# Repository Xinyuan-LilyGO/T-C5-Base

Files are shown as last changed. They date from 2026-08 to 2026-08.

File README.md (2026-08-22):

<div align="center" markdown="1">
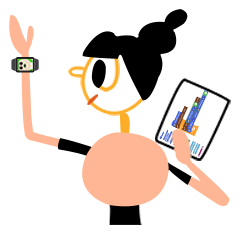
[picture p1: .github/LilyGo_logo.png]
LilyGo logo
  
</div>

<h1 align="center">LilyGo T-C5-Base</h1>

<p align="center">
  <a href="README_CN.md">中文</a>
</p>

## Contents

- [Contents](#contents)
- [Product Description](#product-description)
- [Quick Start](#quick-start)
  - [PlatformIO Quick Start](#platformio-quick-start)
  - [Arduino IDE Quick Start](#arduino-ide-quick-start)
  - [ESP-IDF Quick Start](#esp-idf-quick-start)
- [Examples](#examples)
- [Hardware Notes](#hardware-notes)
  - [CAN Pins](#can-pins)
  - [RS485 Pins](#rs485-pins)
  - [LED Pin](#led-pin)
- [Wiring Notes](#wiring-notes)
- [Speed Summary](#speed-summary)
- [Electrical Parameters](#electrical-parameters)
- [LED Description](#led-description)
- [FAQ](#faq)
  - [Why not use the official PlatformIO `platform = espressif32`?](#why-not-use-the-official-platformio-platform--espressif32)
  - [Build reports that the `t-c5-base` board cannot be found](#build-reports-that-the-t-c5-base-board-cannot-be-found)
  - [Unable to upload or flash](#unable-to-upload-or-flash)
  - [CAN reports `bus_off`, `state=passive`, or `RX=0`](#can-reports-bus_off-statepassive-or-rx0)
  - [Can CAN go above 1 Mbit/s?](#can-can-go-above-1-mbits)
  - [Why is the RS485 maximum speed 5 Mbps?](#why-is-the-rs485-maximum-speed-5-mbps)
  - [RS485 has no data or persistent bad frames](#rs485-has-no-data-or-persistent-bad-frames)
  - [Boot log reports **psram_mspi: Failed to allocate dummy cacheline for PSRAM memory barrier!**](#boot-log-reports-psram_mspi-failed-to-allocate-dummy-cacheline-for-psram-memory-barrier)
- [Resources](#resources)
  - [Schematic](#schematic)
  - [PCB Dimensions](#pcb-dimensions)

## Product Description

This repository provides Arduino and ESP-IDF test examples for the LilyGo T-C5-Base. It covers dual CAN, dual RS485, CAN speed tests, RS485 speed tests, and Modbus RTU over RS485.

Main features:

- RISC-V MCU with 2.4 and 5 GHz dual-band Wi-Fi 6, Bluetooth 5 (LE), and IEEE 802.15.4 (Zigbee, Thread)
- Non-isolated RS485 and CAN transceivers
- 7 to 40 V DC input through an XT30 connector
- Stackable expansion design, supporting up to RS485 x2 and CAN x2 at the same time
- Reserved PCB connector for a 0.96 inch OLED display
- Onboard BOOT and RST buttons
- 2 x 12 pin 2.54 mm headers
- CAN up to 1 Mbps
- RS485 up to 5 Mbps
- Removable termination resistor

## Quick Start

### PlatformIO Quick Start

> [!IMPORTANT]
>
> Do not use the official PlatformIO `platform = espressif32`. Common official PlatformIO Espressif32 releases do not correctly support the ESP32-C5 Arduino environment used by this project. Use the **pioarduino** Espressif32 platform instead.
>

1. Install [Visual Studio Code](https://code.visualstudio.com/) and the **pioarduino** extension.
2. Follow the current [pioarduino](https://github.com/pioarduino/pioarduino-vscode-ide) instructions to install the pioarduino Espressif32 platform.
3. Make sure `platformio.ini` uses the pioarduino platform and enables this repository's local board definition:

   ```ini
   [platformio]
   src_dir = examples/can_dual_speed_test
   boards_dir = board

   [env:t-c5-base]
   board = t-c5-base
   platform = https://github.com/pioarduino/platform-espressif32/releases/download/stable/platform-espressif32.zip
   framework = arduino
   upload_speed = 921600
   monitor_speed = 115200
   ```

4. Change `src_dir` in `platformio.ini` to select the example you want to build.
5. Build:

   ```bash
   pio run
   ```

6. Upload:

   ```bash
   pio run -t upload --upload-port COM76
   ```

7. Open the serial monitor:

   ```bash
   pio device monitor -p COM76 -b 115200
   ```

### Arduino IDE Quick Start

1. Install [Arduino IDE](https://www.arduino.cc/en/software).
2. Install [ESP32 Arduino core](https://docs.espressif.com/projects/arduino-esp32/en/latest/) with ESP32-C5 support.
3. Select the `ESP32C5 Dev Module` board, and set the other options according to the table below.

    | Name                                 | Value                                                |
    | ------------------------------------ | ---------------------------------------------------- |
    | Board                                | **ESP32C5 Dev Module**                               |
    | Port                                 | Your port                                            |
    | USB CDC On Boot                      | Enable                                               |
    | CPU Frequency                        | 240MHZ(WiFi)                                         |
    | Core Debug Level                     | None                                                 |
    | Erase All Flash Before Sketch Upload | Disable                                              |
    | Flash Mode                           | QIO                                                  |
    | Flash Frequency                      | 80MHz                                                |
    | Flash Size                           | **16MB(128Mb)**                                      |
    | Arduino Runs On                      | Core1                                                |
    | Partition Scheme                     | **16M Flash (3MB APP/9.9MB FATFS)**                  |
    | PSRAM                                | CAN and basic examples can use Enabled. Dual RS485 speed tests are recommended to use Disabled. |
    | Upload Speed                         | 921600                                               |

4. Open any `.ino` file under `examples/`.
5. Select the board serial port.
6. Compile and upload.

Build an example with `arduino-cli`:

```bash
arduino-cli compile -b esp32:esp32:esp32c5:CDCOnBoot=cdc,FlashSize=16M,PartitionScheme=app3M_fat9M_16MB,PSRAM=enabled examples/can_basic_echo/can_basic_echo.ino
```

> [!IMPORTANT]
>
> 1. Dual RS485 tests need USB CDC for logs because UART0/Serial0 is used by RS4851. `ARDUINO_USB_CDC_ON_BOOT=1` is already enabled in `board/t-c5-base.json`.
>
> 2. If you use only **T-C5-Base**, only the **blink** and **wifi_scan** examples in this repository are usable. CAN and RS485 examples require the matching Shield.
>

### ESP-IDF Quick Start

ESP-IDF examples are located in `idf-examples/`. The ESP-IDF version used by this project is:

- Branch: `release/v6.1`
- `ESP-IDF v6.1-dev-6068-g6a9c44fe7e`
- Git commit: `6a9c44fe7e`
- Test target: `esp32c5`
- If this is your first time using ESP-IDF, see the [ESP-IDF Programming Guide](https://docs.espressif.com/projects/esp-idf/en/release-v6.1/esp32c5/index.html).

Build on WSL/Linux:

```bash
git clone --recursive -b release/v6.1 https://github.com/espressif/esp-idf.git
cd esp-idf
./install.sh esp32c5
. ./export.sh
cd ..
git clone https://github.com/Xinyuan-LilyGO/T-C5-Base.git
cd T-C5-Base/idf-examples/idf_can_dual_basic_echo
idf.py set-target esp32c5
idf.py build
```

If the ESP-IDF environment can access the serial port directly, flash and monitor with:

```bash
idf.py -p COM76 flash monitor
```

If WSL cannot open the Windows `COMx` port directly, build with `idf.py build` in WSL first, then flash from Windows PowerShell with `esptool.exe`:

```powershell
esptool.exe --chip esp32c5 -p COM76 -b 460800 --before default-reset --after hard-reset write-flash --flash-mode dio --flash-size 16MB --flash-freq 80m 0x2000 .\build\bootloader\bootloader.bin 0x8000 .\build\partition_table\partition-table.bin 0x10000 .\build\idf_can_dual_basic_echo.bin
```

The default serial monitor baud rate is `115200`.

## Examples

Arduino examples:

| Example | Type | Description |
| --- | --- | --- |
| `examples/blink` | Basic | GPIO8 green LED blinking example. CAN/RS485 Shield is not required. |
| `examples/wifi_scan` | Basic | Wi-Fi scan example. CAN/RS485 Shield is not required. |
| `examples/can_basic_echo` | CAN | Single CAN echo. Select CAN1 or CAN2 with `ACTIVE_CAN`; received frames are sent back unchanged. Requires two boards or another CAN node for ACK. |
| `examples/can_dual_basic_echo` | CAN | Single-board dual CAN echo-back. CAN1 sends to CAN2, then CAN2 echoes back to CAN1. Supports OLED PASS/FAIL display, and GPIO8 LED blinks for 300 ms when the test passes. |
| `examples/can_speed_test` | CAN | Single CAN speed test. Normal mode requires two boards or another CAN node. |
| `examples/can_dual_speed_test` | CAN | Dual CAN mutual speed test. Connect CAN1/CAN2 on the same board to the same CAN bus for mutual TX/RX. Supports OLED status display. |
| `examples/can_advanced` | CAN | Dual CAN forwarding and diagnostics example, including filtering and bus-off recovery logic. |
| `examples/rs485_basic_echo` | RS485 | Single RS485 echo. Select RS4851 or RS4852 with `ACTIVE_RS485`; serial monitor input is sent to the RS485 bus, and bus data is printed back to serial. |
| `examples/rs485_dual_basic_echo` | RS485 | Single-board dual RS485 echo-back. RS4851 sends to RS4852, then RS4852 echoes back to RS4851. Supports OLED PASS/FAIL display, and GPIO8 LED blinks for 300 ms when the test passes. |
| `examples/rs485_speed_test` | RS485 | Single RS485 speed test. |
| `examples/rs485_dual_speed_test` | RS485 | Dual RS485 mutual speed test using Arduino `HardwareSerial` and manual DE control. |
| `examples/rs485_dual_driver_speed_test` | RS485 | Dual RS485 Arduino API speed test, used to verify the stable speed of a pure Arduino implementation. |
| `examples/rs485_modbus_module` | RS485 | Modbus RTU host example. The default function code is `0x03`. |
| `examples/can_rs485_dual_echo_back` | Combined  | Single-board dual CAN plus dual RS485 echo-back test, used to verify CAN/RS485 Shield operation at the same time. |

> [!NOTE]
>
> CAN and RS485 examples require the matching Shield. `can_dual_basic_echo`, `can_dual_speed_test`, and `can_rs485_dual_echo_back` need CAN1_H/CAN2_H and CAN1_L/CAN2_L connected to the same CAN bus, with the 120R resistor jumper installed.
>
> `rs485_dual_basic_echo`, `rs485_dual_speed_test`, and `rs485_dual_driver_speed_test` need RS4851_A/RS4852_A and RS4851_B/RS4852_B connected together. For high-speed or long-cable tests, install the 120R termination resistor jumper.

- For more ESP32-C5 examples, see [arduino-esp32-libraries](https://github.com/espressif/arduino-esp32/tree/master/libraries).

ESP-IDF examples:

| Example | Type  | Description |
| --- | ----- | --- |
| `idf-examples/idf_can_dual_basic_echo` | CAN | ESP-IDF dual CAN echo-back example. CAN1 sends to CAN2, then CAN2 echoes back to CAN1. Default `1 Mbit/s`, pure ESP-IDF TWAI on-chip API. |
| `idf-examples/idf_rs485_dual_speed_test` | RS485 | ESP-IDF dual RS485 speed test using the ESP-IDF UART RS485 driver. Tested stable at `5 Mbps` with 25 m cable and 120R termination. |

> [!NOTE]
>
> `idf_can_dual_basic_echo` was tested with `ESP-IDF v6.1-dev-6940-g08e0d30a74`, target chip `esp32c5`, and COM76. During an 18-second run, 9 echo-back tests passed with `fail=0`, `busErr=0/0`, and `isrDrop=0/0`.

## Hardware Notes

### CAN Pins

| ESP32-C5 | SN65HVD231DR |
| --- | --- |
| GPIO26 | CAN1_TX |
| GPIO25 | CAN1_RX |
| GPIO0 | CAN2_TX |
| GPIO1 | CAN2_RX |

### RS485 Pins

| ESP32-C5 | SP3485EEN |
| --- | --- |
| GPIO4 | RS4851_RX |
| GPIO5 | RS4851_TX |
| GPIO27 | RS4851_DTR / RTS |
| GPIO24 | RS4852_RX |
| GPIO23 | RS4852_TX |
| GPIO7 | RS4852_DTR / RTS |

### LED Pin

| ESP32-C5 | LED |
| --- | ----- |
| GPIO8 | Green |

## Wiring Notes

- Normal CAN mode requires at least two CAN nodes. A single CAN node has no ACK and may report TX failure or bus-off.
- `can_dual_speed_test` uses CAN1 and CAN2 on the same board as two CAN nodes. Connect CAN1_H to CAN2_H and CAN1_L to CAN2_L on the same CAN bus.
- The CAN bus needs proper termination at the physical ends. A 120R termination resistor is recommended for normal tests, especially at 500 kbit/s and 1 Mbit/s.
- By default, the onboard 120R termination resistor is already shorted by the jumper cap.
- RS485 A/B must be connected with the correct polarity. If there is no data or bad frames persist, swap A/B and test again.
- RS485 wiring should consider common ground, termination, cable length, and baud rate according to the actual site.
- The GND pin on the CAN and RS485 3-pin connector usually does not need to be connected. Connect GND if shielding or grounding is required.
- GPIO15 is not available and is not routed to the 12-pin connector. Do not control GPIO15 in software, because GPIO15 is connected to the internal PSRAM. Controlling GPIO15 may cause a crash.

## Speed Summary

| Interface | Condition | Highest stable result |
| --- | --- | --- |
| CAN | 25 m twisted pair cable, with 120R termination | 1 Mbit/s |
| CAN | 20 cm Dupont wire, without 120R termination | 125 kbit/s |
| RS485 | 25 m cable, with 120R, Arduino-ESP32 4.0.0-alpha1 | 5 Mbps |
| RS485 | 25 m cable, with 120R, ESP-IDF UART RS485 driver | 5 Mbps |

CAN has been confirmed at the standard Classic CAN rate of **1 Mbit/s**.

## Electrical Parameters

| Feature | Details |
| --- | --- |
| USB-C input voltage | 5V |
| XT30 DC input range | 7-40V |
| 3.3V header output current capability | 500mA |

> [!IMPORTANT]
>
> 1. It is not recommended to draw 2A from the 5V interface for a long time. If long-term high load is required, provide proper heat dissipation.
>
> 2. It is not recommended to connect a 40V power supply to the XT30 input. Use less than 40V. If a 40V input supply is used, make sure it is a stable voltage source, because 40V is the maximum rating of the power chip.
>
> 3. The current capability of the 5V header depends on the connected power source when USB-C is used. When XT30 is used, the maximum is 2A.
>

## LED Description

| Description | Color |
| --- | ----- |
| 3.3V power indicator | Red |
| 5V power indicator | Red |
| GPIO8 control | Green |

## FAQ

### Why not use the official PlatformIO `platform = espressif32`?

Common official PlatformIO Espressif32 releases do not correctly support the ESP32-C5 Arduino environment used by this project. Use the pioarduino Espressif32 platform.

### Build reports that the `t-c5-base` board cannot be found

Make sure `platformio.ini` contains:

```ini
boards_dir = board
board = t-c5-base
```

The local board definition file is located at `board/t-c5-base.json`.

### Unable to upload or flash

Try entering download mode manually:

1. Hold BOOT.
2. Press RST briefly.
3. Release BOOT.
4. Run the upload command again.

Also make sure the upload port is correct, for example `COM76` on Windows.

### CAN reports `bus_off`, `state=passive`, or `RX=0`

Check that CAN-H/CAN-L are connected correctly. Make sure there are at least two CAN nodes on the bus and add 120R termination resistors at both ends. In testing, a 20 cm cable without 120R was only stable up to 125 kbit/s. With 120R, it reached 1 Mbit/s.

### Can CAN go above 1 Mbit/s?

The standard Classic CAN rate is usually up to 1 Mbit/s. ESP32-C5 supports a maximum CAN communication rate of 1 Mbps.

### Why is the RS485 maximum speed 5 Mbps?

ESP32-C5 supports a maximum communication rate of 5 Mbps.

### RS485 has no data or persistent bad frames

Check A/B polarity first, then common ground, termination resistor, baud rate, and whether the correct RS485 channel is enabled in the example.

### Boot log reports **psram_mspi: Failed to allocate dummy cacheline for PSRAM memory barrier!**

```sh
ESP-ROM:esp32c5-eco3-20250704
Build:Jul  4 2025
rst:0x15 (USB_UART_HPSYS),boot:0x1e (SPI_FAST_FLASH_BOOT)
SPI mode:DIO, clock div:1
load:0x408556c0,len:0x1254
load:0x4084bba0,len:0xc20
load:0x4084e5a0,len:0x3270
entry 0x4084bba0
E (1023) psram_mspi: Failed to allocate dummy cacheline for PSRAM memory barrier!
```

- See the official note: [arduino-esp32/issues/12587](https://github.com/espressif/arduino-esp32/issues/12587)

## Resources

### Schematic

- [T-C5-Base](./schematic/T-C5-Base.pdf)
- [T-C5-CAN-Shield](./schematic/T-C5-CAN-Shield.pdf)
- [T-C5-RS485-Shield](./schematic/T-C5-RS485-Shield.pdf)

### PCB Dimensions

- [T-C5-Base SVG](./dimensions/T-C5-Base.svg)
- [T-C5-CAN-Shield SVG](./dimensions/T-C5-CAN-Shield.svg)
- [T-C5-RS485-Shield SVG](./dimensions/T-C5-RS485-Shield.svg)
- [T-C5-Base DXF](./dimensions/T-C5-Base.dxf)
- [T-C5-CAN-Shield DXF](./dimensions/T-C5-CAN-Shield.dxf)
- [T-C5-RS485-Shield DXF](./dimensions/T-C5-RS485-Shield.dxf)

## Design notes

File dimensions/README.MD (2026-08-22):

# T-C5-Base

- [T-C5-Base SVG](./T-C5-Base.svg)
- [T-C5-Base DXF](./T-C5-Base.dxf)

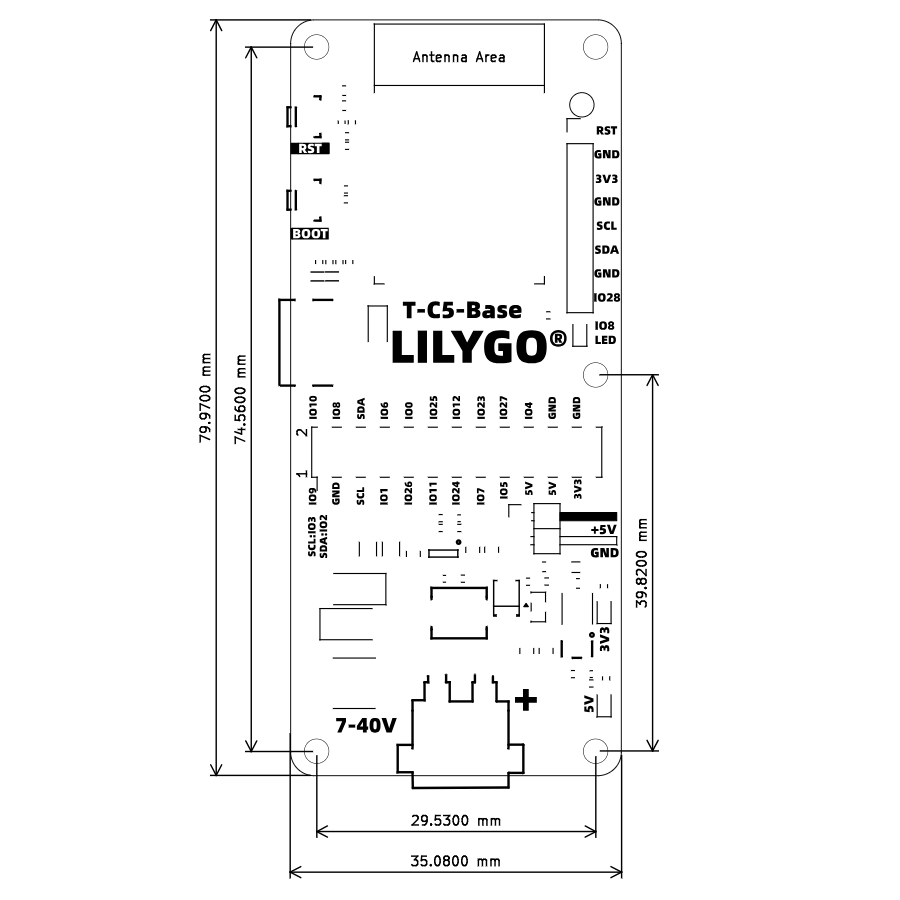
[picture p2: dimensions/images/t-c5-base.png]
T-C5-Base


# T-C5-Rs485-Shield

- [T-C5-Rs485-Shield SVG](./T-C5-Rs485-Shield.svg)
- [T-C5-Rs485-Shield DXF](./T-C5-Rs485-Shield.dxf)

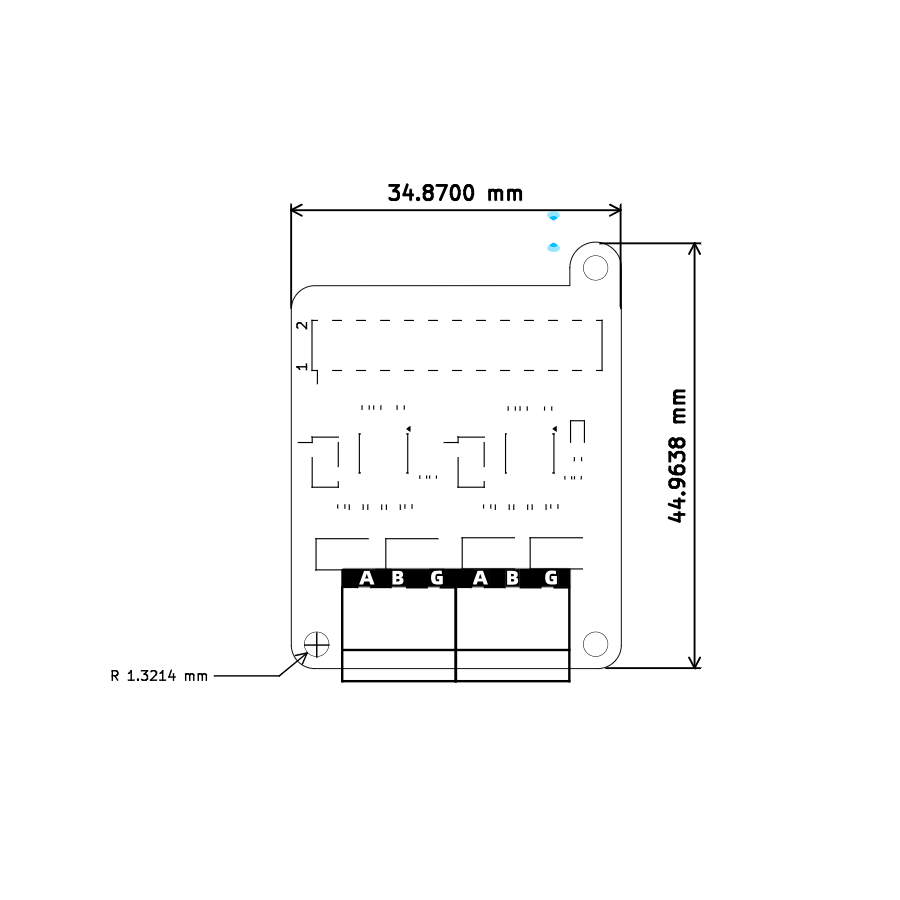
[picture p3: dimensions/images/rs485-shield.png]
T-C5-Rs485-Shield


# T-C5-Can-Shield

- [T-C5-CAN-Shield SVG](./T-C5-CAN-Shield.svg)
- [T-C5-CAN-Shield DXF](./T-C5-CAN-Shield.dxf)

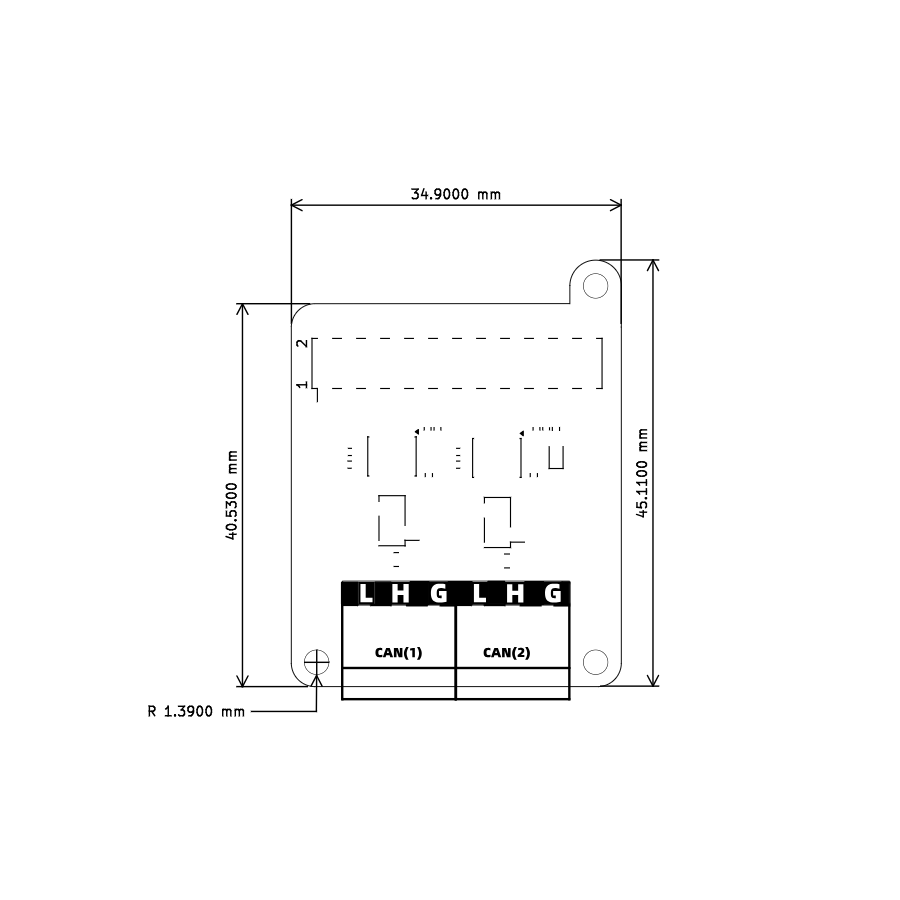
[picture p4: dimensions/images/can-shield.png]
T-C5-Can-Shield


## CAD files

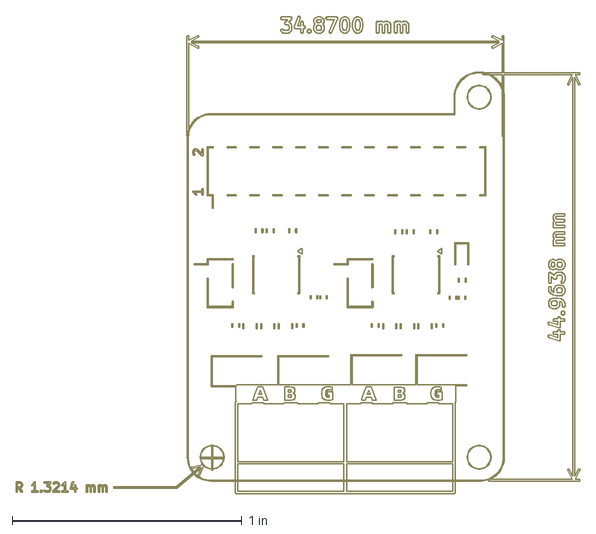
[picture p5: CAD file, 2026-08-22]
dimensions/T-C5-RS485-Shield.dxf
2.46 x 2.08 in

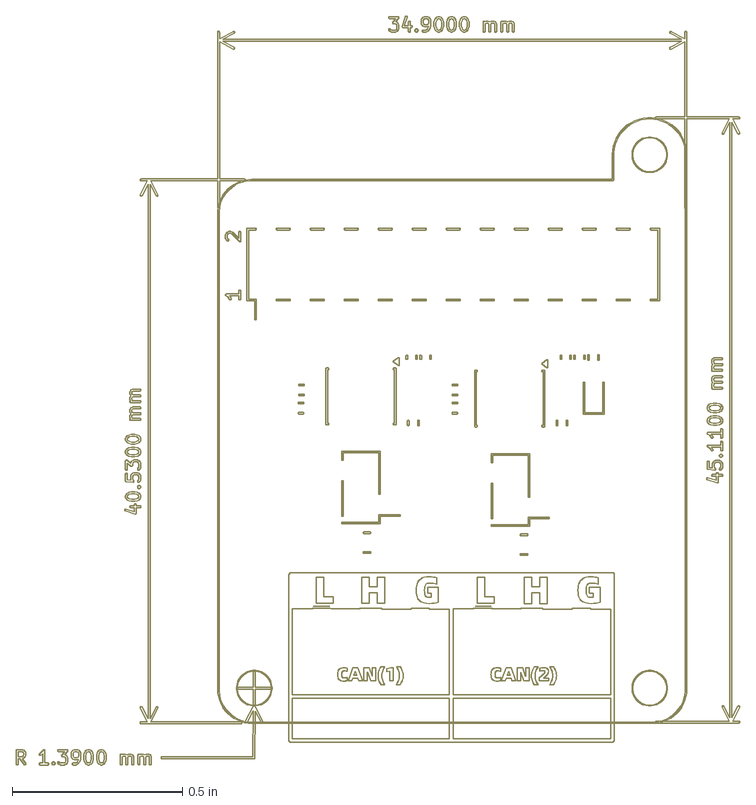
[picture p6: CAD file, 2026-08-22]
dimensions/T-C5-CAN-Shield.dxf
2.13 x 2.20 in

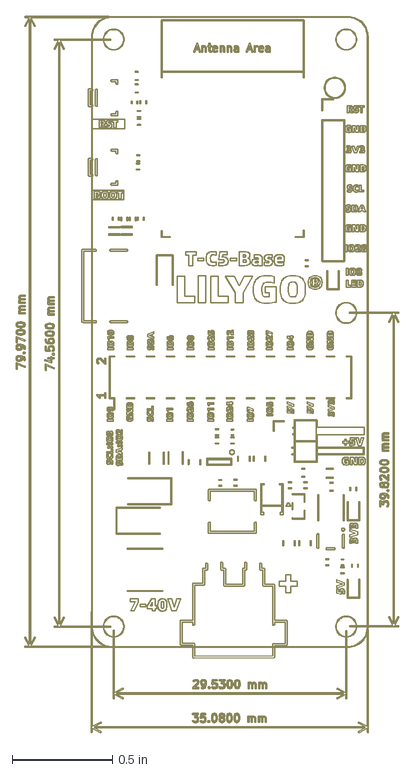
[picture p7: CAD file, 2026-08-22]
dimensions/T-C5-Base.dxf
1.91 x 3.58 in

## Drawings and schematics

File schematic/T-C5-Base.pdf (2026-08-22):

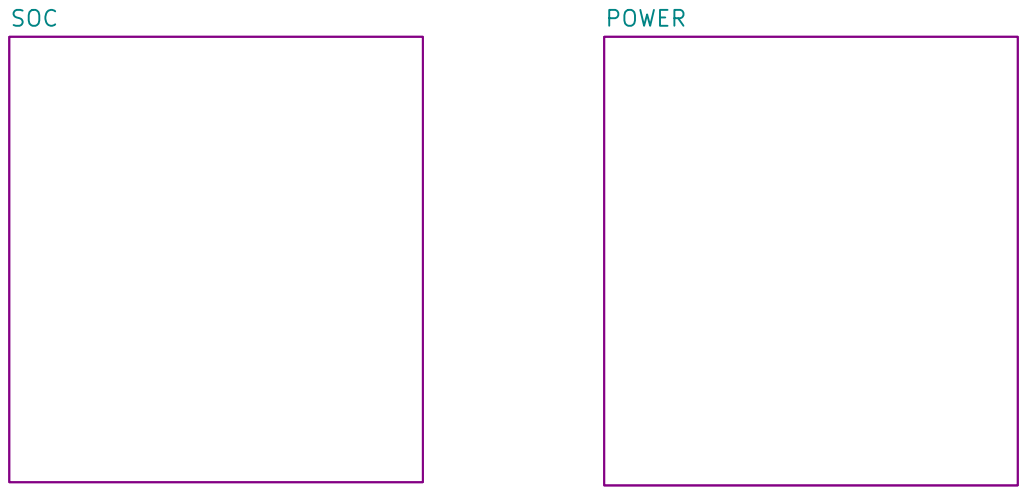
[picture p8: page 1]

Size: A4 | | V1.0 Rev:
KiCad E.D.A. 10.0.5 | RevAuthor:Lewis He | Id: 1/3

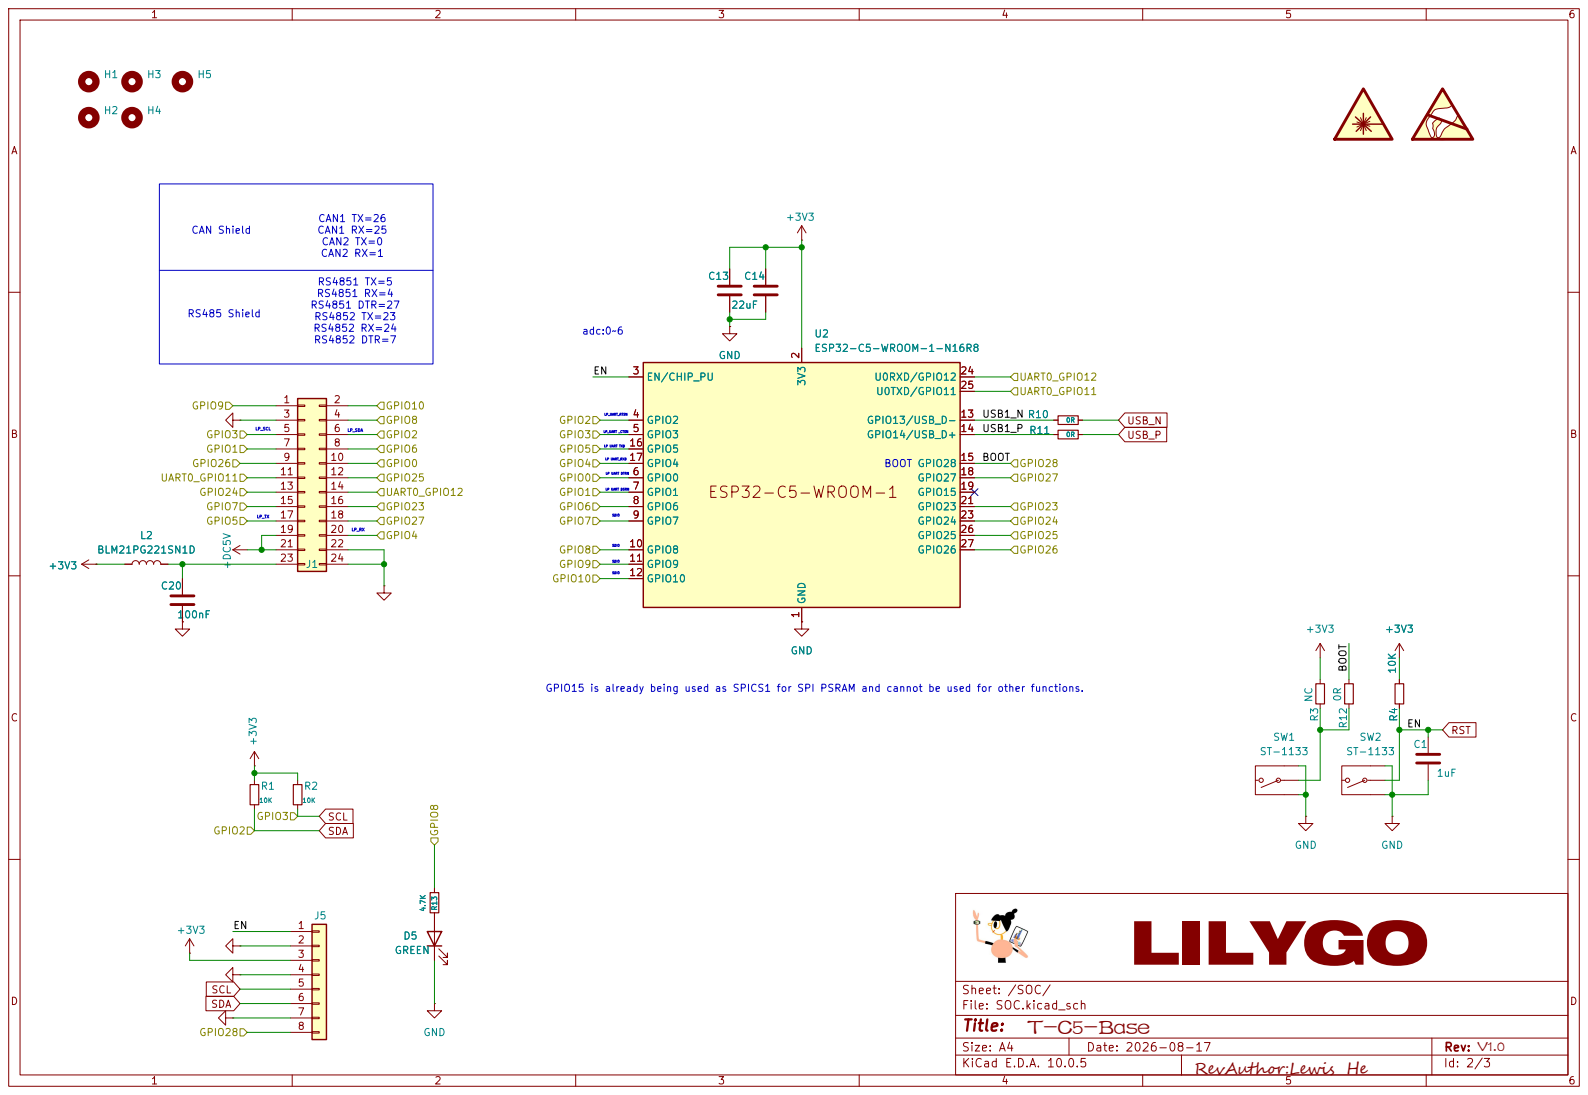
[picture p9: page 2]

LP UART TXD CAN1 TX=26 CAN1 RX=25 CAN2 TX=0 CAN2 RX=1

Size: A4 | | V1.0 Rev:

RevAuthor:Lewis He

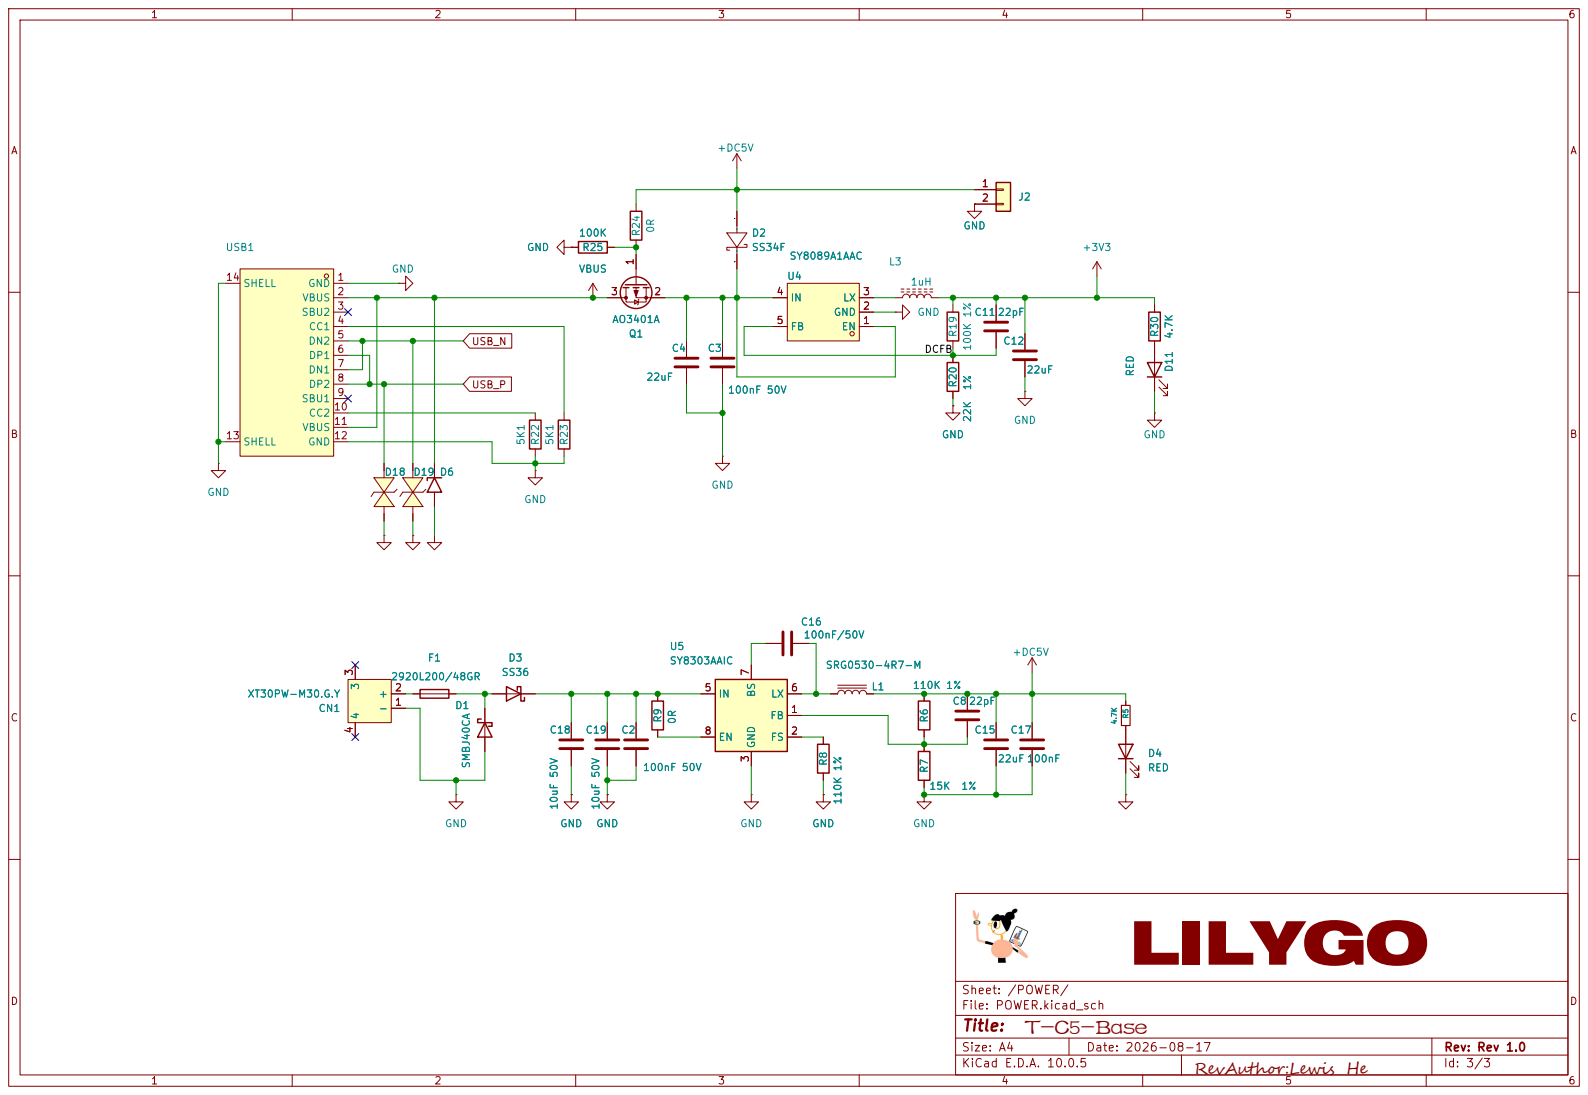
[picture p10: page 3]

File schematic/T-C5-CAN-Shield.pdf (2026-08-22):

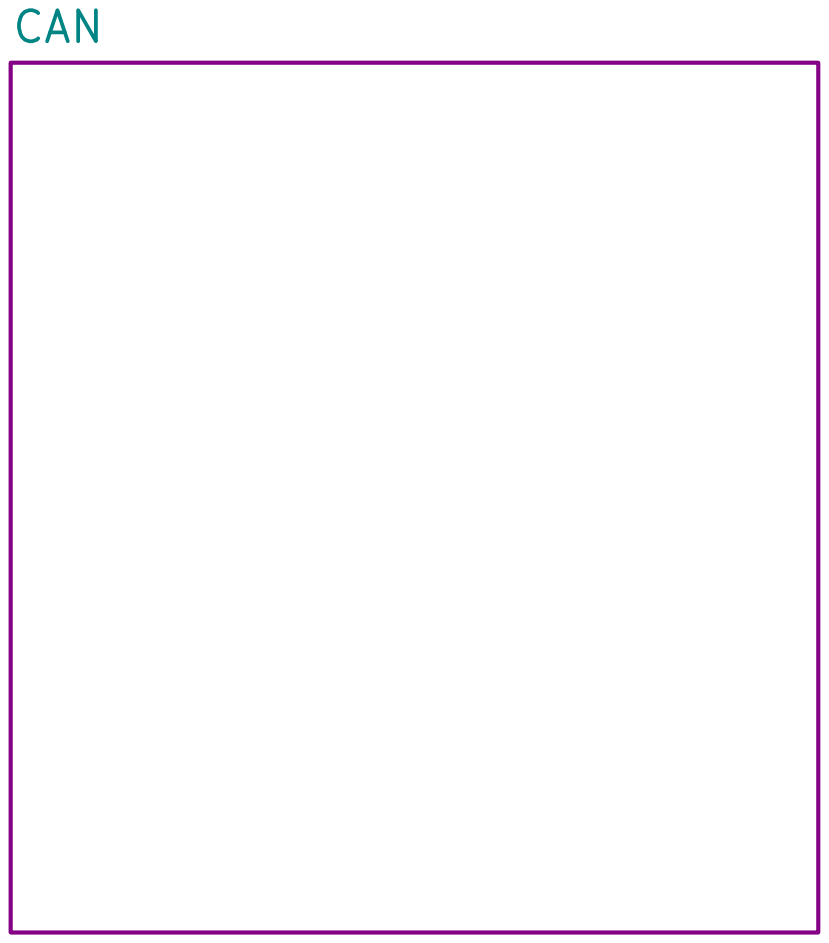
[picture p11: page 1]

Size: A4 | | V1.0 Rev:
KiCad E.D.A. 10.0.5 | RevAuthor:Lewis He | Id: 1/2

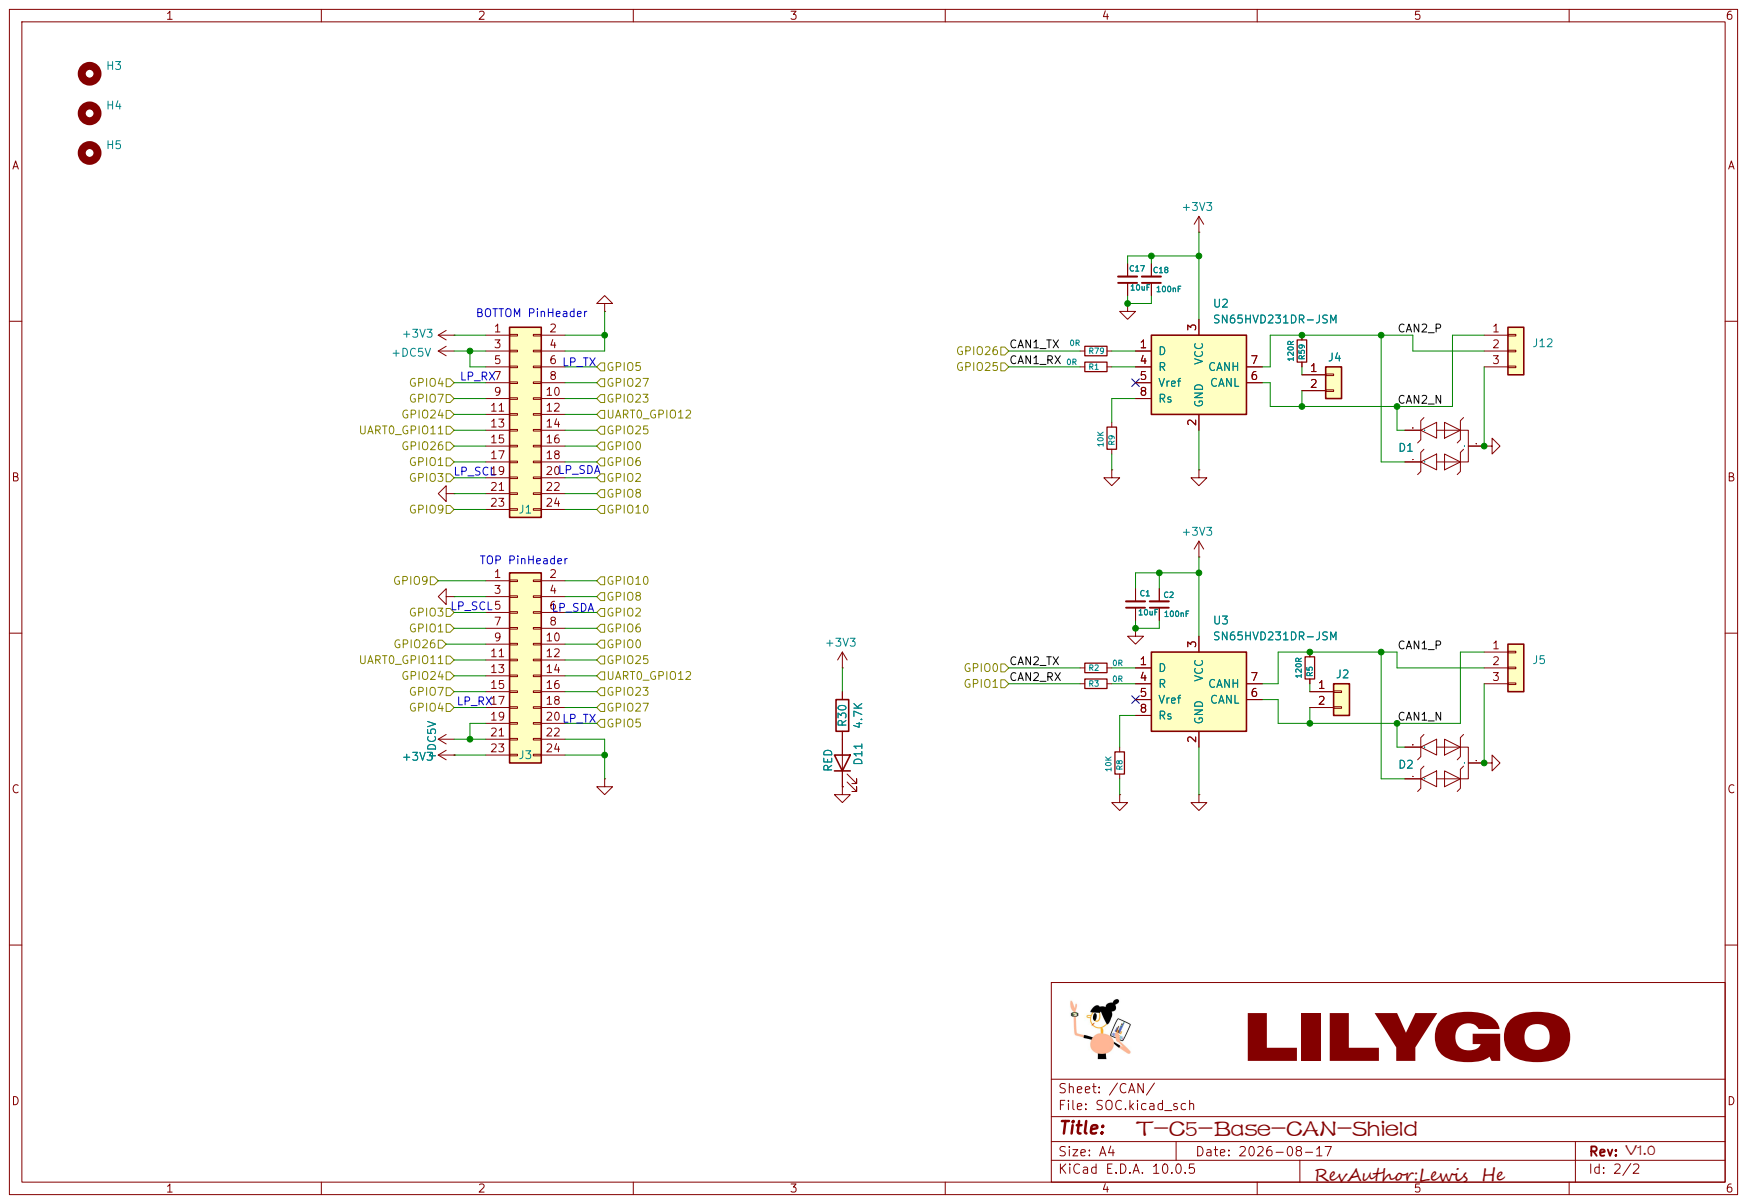
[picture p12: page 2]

Size: A4 | Rev:
KiCad E.D.A. 10.0.5 | Id: 2/2

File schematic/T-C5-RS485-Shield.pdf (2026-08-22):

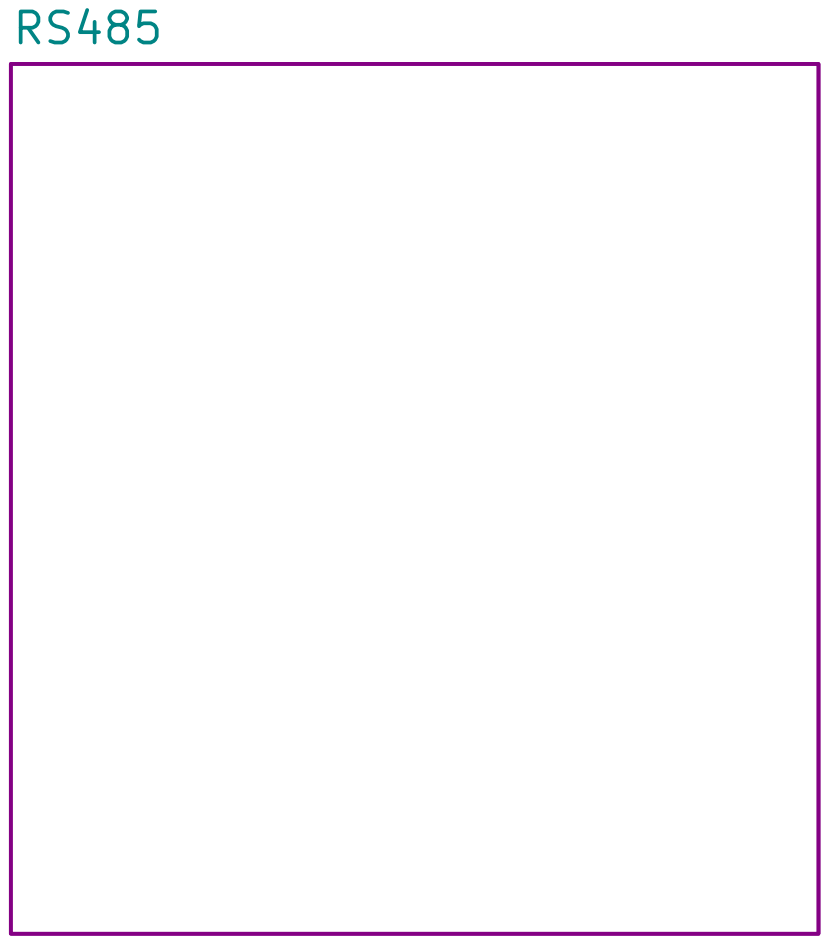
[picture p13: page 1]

Size: A4 | | V1.0 Rev:
KiCad E.D.A. 10.0.5 | RevAuthor:Lewis He | Id: 1/2

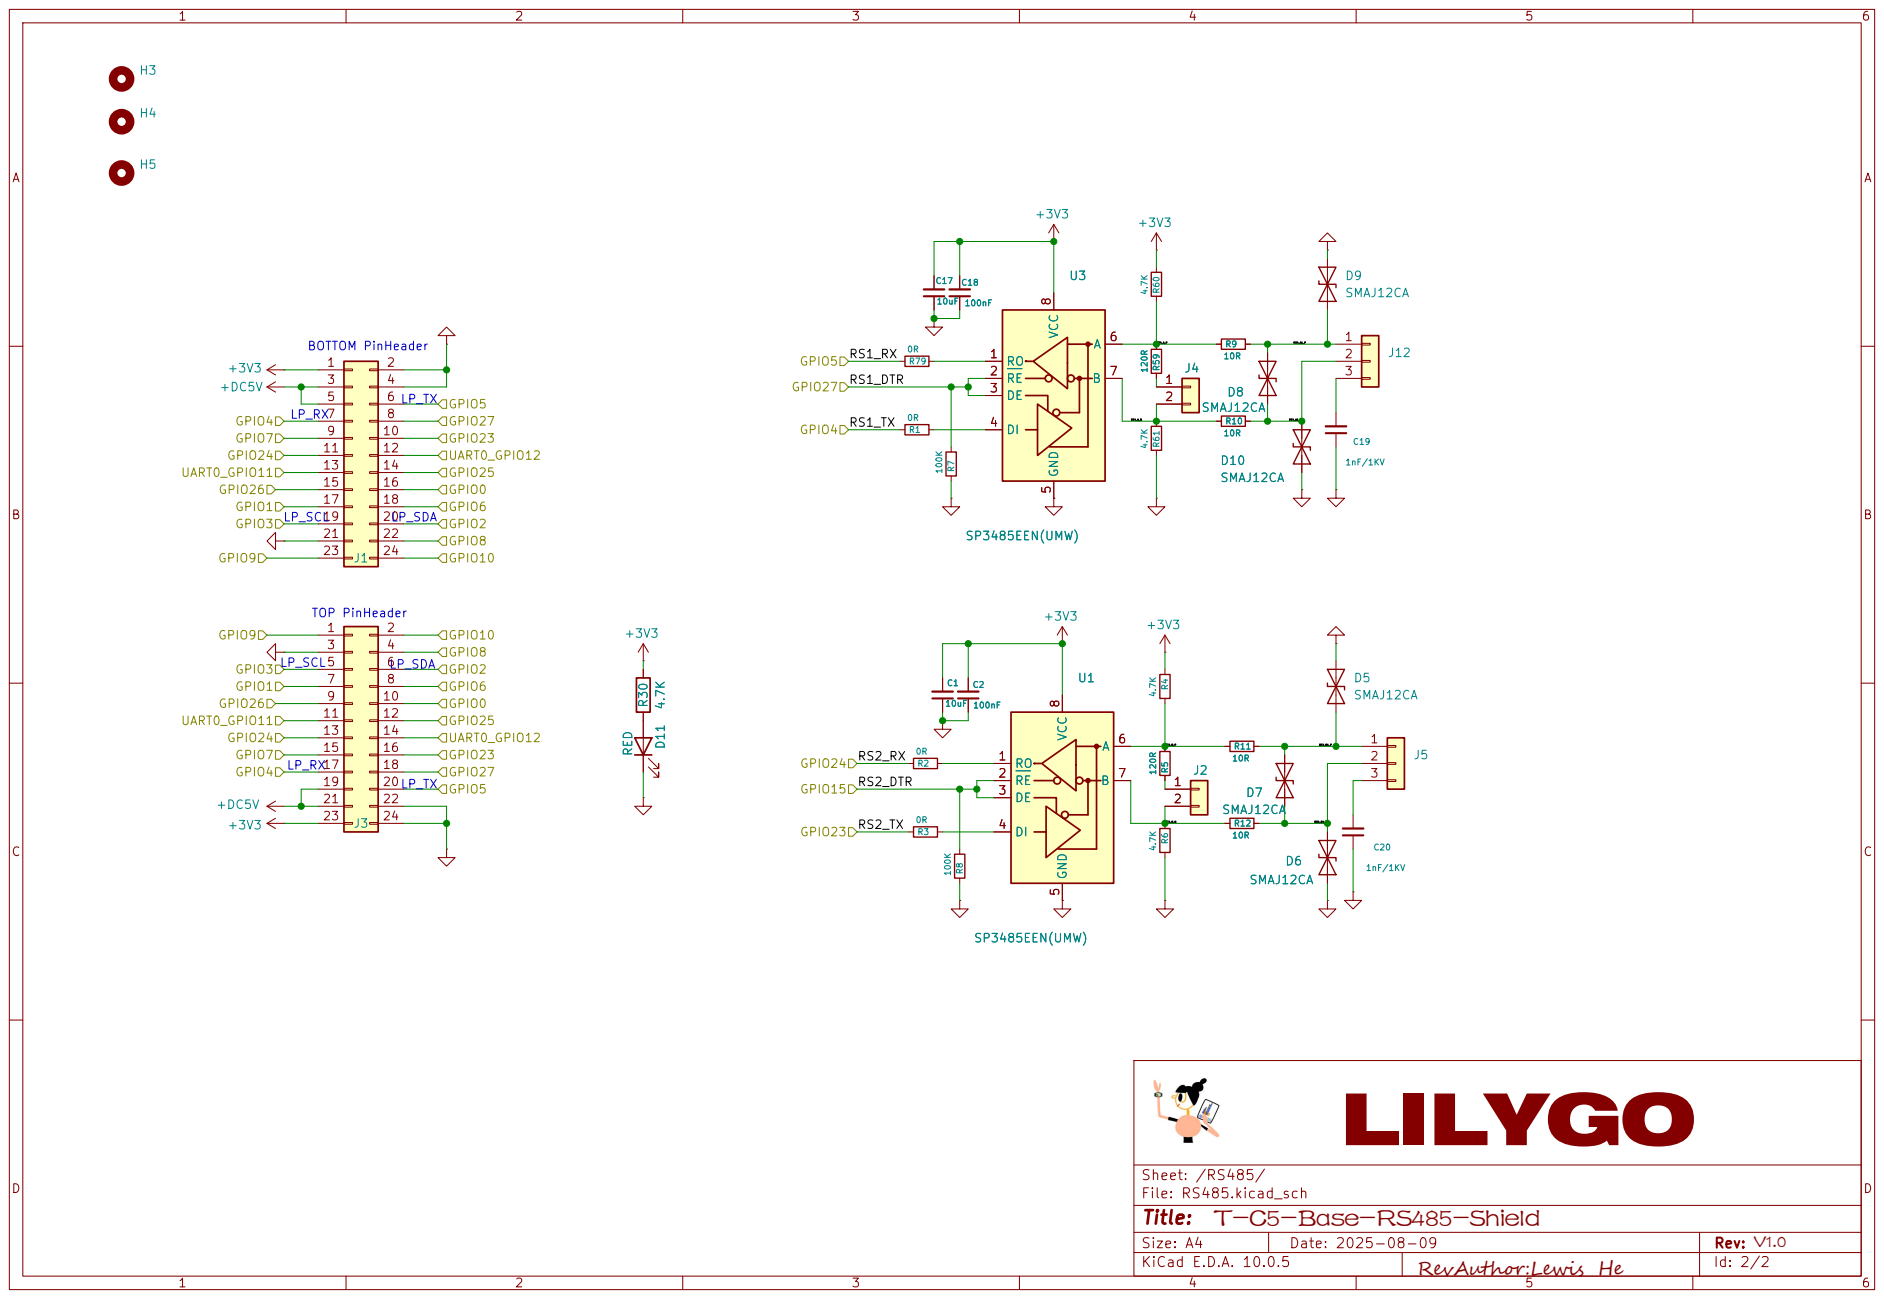
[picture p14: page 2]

Size: A4 | | V1.0 Rev:
KiCad E.D.A. 10.0.5 | RevAuthor:Lewis He | Id: 2/2

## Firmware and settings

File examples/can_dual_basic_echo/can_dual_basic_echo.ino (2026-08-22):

/**
 * @file      can_dual_basic_echo.ino
 * @author    Lewis He (lewishe@outlook.com)
 * @license   MIT
 * @copyright Copyright (c) 2026  ShenZhen XinYuan Electronic Technology Co., Ltd
 * @date      2026-08-21
 * @note      T-C5-Base dual CAN echo-back test with optional OLED status.
 *
 *  Wiring:
 *    CAN1_H <-> CAN2_H
 *    CAN1_L <-> CAN2_L
 *    GND    <-> GND
 *
 *  Add CAN termination according to your wiring. For a normal two-node CAN bus,
 *  use 120 ohm termination at both bus ends.
 *
 *  CAN1 sends a classic CAN frame to CAN2. CAN2 verifies the frame and sends
 *  the same payload back to CAN1 with an echo ID, so this sketch can verify
 *  both CAN transceivers on one board.
 *
 *  Note: Arduino-ESP32 does not currently expose a native Arduino API for both
 *  ESP32-C5 on-chip TWAI controllers, so this CAN example uses ESP-IDF TWAI
 *  driver APIs inside an Arduino sketch.
 */

#include <Arduino.h>
#include <inttypes.h>
#include <string.h>
#include "esp_twai.h"
#include "esp_twai_onchip.h"
#include "freertos/FreeRTOS.h"
#include "freertos/queue.h"

#ifndef CAN_BITRATE
#define CAN_BITRATE 1000000
#endif

#ifndef AUTO_SEND_INTERVAL_MS
#define AUTO_SEND_INTERVAL_MS 2000
#endif

#define CAN1_TO_CAN2_ID 0x321
#define CAN2_TO_CAN1_ID 0x421
#define CAN_RX_TIMEOUT_MS 150
#define CAN_RX_QUEUE_DEPTH 16
#define CAN_TX_QUEUE_DEPTH 2
#define LED_OK_PULSE_MS 300
#define OLED_I2C_ADDRESS 0x3C
#define OLED_SDA_PIN 2
#define OLED_SCL_PIN 3

#ifndef CAN_ENABLE_OLED
#define CAN_ENABLE_OLED 1
#endif

#if CAN_ENABLE_OLED
#include <Wire.h>
#include "SSD1306Wire.h"
#endif

// CAN1 pins
#define CAN1_TX_PIN 26
#define CAN1_RX_PIN 25
// CAN2 pins
#define CAN2_TX_PIN 0
#define CAN2_RX_PIN 1

#ifdef LED_BUILTIN
#undef LED_BUILTIN
#endif

#define LED_BUILTIN     8

struct CanFrame {
    uint32_t id;
    uint8_t dlc;
    bool ide;
    bool rtr;
    uint8_t data[TWAI_FRAME_MAX_LEN];
};

struct CanBus {
    const char *name;
    int txPin;
    int rxPin;
    twai_node_handle_t node;
    QueueHandle_t rxQueue;
    twai_frame_t txFrame;
    uint8_t txData[TWAI_FRAME_MAX_LEN];
    volatile bool busOffSeen;
    volatile uint32_t isrDrops;
    volatile uint32_t txOk;
    volatile uint32_t txFail;
    volatile uint32_t busErrors;
    bool started;
};

static CanBus can1 = {"CAN1", CAN1_TX_PIN, CAN1_RX_PIN, nullptr, nullptr, {}, {}, false, 0, 0, 0, 0, false};
static CanBus can2 = {"CAN2", CAN2_TX_PIN, CAN2_RX_PIN, nullptr, nullptr, {}, {}, false, 0, 0, 0, 0, false};
static uint32_t frameSeq = 0;
static uint32_t lastAutoSendMs = 0;
static uint32_t echoOkCount = 0;
static uint32_t echoFailCount = 0;
static bool lastForwardOk = false;
static bool lastBackOk = false;
static bool lastEchoOk = false;
static bool hasEchoResult = false;
static bool ledPulseActive = false;
static uint32_t ledOffMs = 0;

#if CAN_ENABLE_OLED
SSD1306Wire oled(OLED_I2C_ADDRESS, OLED_SDA_PIN, OLED_SCL_PIN);
static bool oledReady = false;
#endif

static uint8_t checksumPayload(const uint8_t *data, size_t len)
{
    uint8_t sum = 0x5A;
    for (size_t i = 0; i < len; ++i) {
        sum = (uint8_t)((sum << 1) | (sum >> 7));
        sum ^= data[i];
    }
    return sum;
}

static void fillPayload(uint8_t *data, uint32_t sequence)
{
    data[0] = 0xC5;
    memcpy(&data[1], &sequence, sizeof(sequence));
    data[5] = 0x5C;
    data[6] = (uint8_t)(sequence ^ (sequence >> 8) ^ (sequence >> 16) ^ (sequence >> 24));
    data[7] = checksumPayload(data, 7);
}

static bool verifyPayload(const CanFrame &frame, uint32_t expectedId, uint32_t sequence)
{
    if (frame.ide || frame.rtr || frame.id != expectedId || frame.dlc != 8) {
        return false;
    }

    uint32_t rxSequence = 0;
    memcpy(&rxSequence, &frame.data[1], sizeof(rxSequence));
    return frame.data[0] == 0xC5 &&
           rxSequence == sequence &&
           frame.data[5] == 0x5C &&
           frame.data[6] == (uint8_t)(sequence ^ (sequence >> 8) ^ (sequence >> 16) ^ (sequence >> 24)) &&
           frame.data[7] == checksumPayload(frame.data, 7);
}

static void initLed()
{
    pinMode(LED_BUILTIN, OUTPUT);
    digitalWrite(LED_BUILTIN, LOW);
}

static void pulseOkLed()
{
    digitalWrite(LED_BUILTIN, HIGH);
    ledPulseActive = true;
    ledOffMs = millis() + LED_OK_PULSE_MS;
}

static void updateOkLed()
{
    if (ledPulseActive && (int32_t)(millis() - ledOffMs) >= 0) {
        digitalWrite(LED_BUILTIN, LOW);
        ledPulseActive = false;
    }
}

static String bitrateLabel()
{
    if (CAN_BITRATE >= 1000000 && (CAN_BITRATE % 1000000) == 0) {
        return String(CAN_BITRATE / 1000000) + "Mbps";
    }
    if (CAN_BITRATE >= 1000 && (CAN_BITRATE % 1000) == 0) {
        return String(CAN_BITRATE / 1000) + "Kbps";
    }
    return String(CAN_BITRATE) + "bps";
}

#if CAN_ENABLE_OLED
static void drawCenteredText(int16_t y, const String &text)
{
    if (!oledReady) {
        return;
    }

    oled.setTextAlignment(TEXT_ALIGN_CENTER);
    oled.drawString(64, y, text);
    oled.setTextAlignment(TEXT_ALIGN_LEFT);
}

static void drawOledBoot(const char *status)
{
    if (!oledReady) {
        return;
    }

    oled.clear();
    oled.setFont(ArialMT_Plain_10);
    drawCenteredText(0, "CAN ECHO");
    oled.setFont(ArialMT_Plain_16);
    drawCenteredText(18, status);
    oled.setFont(ArialMT_Plain_10);
    drawCenteredText(42, bitrateLabel());
    oled.display();
}

static void updateOledResult()
{
    if (!oledReady) {
        return;
    }

    oled.clear();
    oled.setFont(ArialMT_Plain_10);
    drawCenteredText(0, "CAN ECHO  " + bitrateLabel());

    oled.setFont(ArialMT_Plain_24);
    drawCenteredText(13, hasEchoResult ? (lastEchoOk ? "PASS" : "FAIL") : "WAIT");

    oled.setFont(ArialMT_Plain_10);
    drawCenteredText(40, String("1>2 ") + (lastForwardOk ? "OK" : "NG") +
                         "    2>1 " + (lastBackOk ? "OK" : "NG"));
    drawCenteredText(52, String("OK:") + String(echoOkCount) +
                         "  NG:" + String(echoFailCount) +
                         "  ERR:" + String(can1.busErrors + can2.busErrors));
    oled.display();
}

static void initOled()
{
#if !CAN_ENABLE_OLED
    Serial.println("[OLED] disabled by CAN_ENABLE_OLED=0");
    return;
#endif

    Wire.begin(OLED_SDA_PIN, OLED_SCL_PIN);
    Wire.beginTransmission(OLED_I2C_ADDRESS);
    if (Wire.endTransmission() != 0) {
        Serial.printf("[OLED] not found at 0x%02X SDA=GPIO%d SCL=GPIO%d\n",
                      OLED_I2C_ADDRESS, OLED_SDA_PIN, OLED_SCL_PIN);
        return;
    }

    oled.init();
    oled.flipScreenVertically();
    oled.setFont(ArialMT_Plain_10);
    oled.setTextAlignment(TEXT_ALIGN_LEFT);
    oled.setContrast(255);
    oledReady = true;
    Serial.printf("[OLED] started, address=0x%02X SDA=GPIO%d SCL=GPIO%d\n",
                  OLED_I2C_ADDRESS, OLED_SDA_PIN, OLED_SCL_PIN);
}
#else
static void drawOledBoot(const char *status)
{
    (void)status;
}

static void updateOledResult()
{
}

static void initOled()
{
    Serial.println("[OLED] disabled by CAN_ENABLE_OLED=0");
}
#endif

static bool IRAM_ATTR onRxDone(twai_node_handle_t handle,
                               const twai_rx_done_event_data_t *eventData,
                               void *userContext)
{
    (void)eventData;
    CanBus *bus = (CanBus *)userContext;

    uint8_t rxData[TWAI_FRAME_MAX_LEN] = {};
    twai_frame_t rxFrame = {};
    rxFrame.buffer = rxData;
    rxFrame.buffer_len = sizeof(rxData);

    BaseType_t taskWoken = pdFALSE;
    if (twai_node_receive_from_isr(handle, &rxFrame) != ESP_OK) {
        bus->isrDrops = bus->isrDrops + 1;
        return taskWoken == pdTRUE;
    }

    CanFrame queuedFrame = {};
    queuedFrame.id = rxFrame.header.id;
    queuedFrame.dlc = rxFrame.header.dlc > TWAI_FRAME_MAX_LEN ? TWAI_FRAME_MAX_LEN : rxFrame.header.dlc;
    queuedFrame.ide = rxFrame.header.ide;
    queuedFrame.rtr = rxFrame.header.rtr;
    memcpy(queuedFrame.data, rxData, queuedFrame.dlc);

    if (xQueueSendFromISR(bus->rxQueue, &queuedFrame, &taskWoken) != pdTRUE) {
        bus->isrDrops = bus->isrDrops + 1;
    }

    return taskWoken == pdTRUE;
}

static bool IRAM_ATTR onTxDone(twai_node_handle_t handle,
                               const twai_tx_done_event_data_t *eventData,
                               void *userContext)
{
    (void)handle;
    CanBus *bus = (CanBus *)userContext;

    if (eventData->is_tx_success) {
        bus->txOk = bus->txOk + 1;
    } else {
        bus->txFail = bus->txFail + 1;
    }
    return false;
}

static bool IRAM_ATTR onError(twai_node_handle_t handle,
                              const twai_error_event_data_t *eventData,
                              void *userContext)
{
    (void)handle;
    CanBus *bus = (CanBus *)userContext;
    if (eventData->err_flags.val) {
        bus->busErrors = bus->busErrors + 1;
    }
    return false;
}

static bool IRAM_ATTR onStateChange(twai_node_handle_t handle,
                                    const twai_state_change_event_data_t *eventData,
                                    void *userContext)
{
    (void)handle;
    CanBus *bus = (CanBus *)userContext;
    if (eventData->new_sta == TWAI_ERROR_BUS_OFF) {
        bus->busOffSeen = true;
    }
    return false;
}

static bool configureAcceptAllFilters(twai_node_handle_t node)
{
    twai_mask_filter_config_t standardFilter = {};
    standardFilter.id = 0;
    standardFilter.mask = 0;
    standardFilter.is_ext = false;
    standardFilter.no_fd = true;

    if (twai_node_config_mask_filter(node, 0, &standardFilter) != ESP_OK) {
        return false;
    }

    twai_mask_filter_config_t extendedFilter = standardFilter;
    extendedFilter.is_ext = true;
    return twai_node_config_mask_filter(node, 1, &extendedFilter) == ESP_OK;
}

static bool startCanBus(CanBus &bus)
{
    bus.rxQueue = xQueueCreate(CAN_RX_QUEUE_DEPTH, sizeof(CanFrame));
    if (bus.rxQueue == nullptr) {
        Serial.printf("[%s] failed to create RX queue\n", bus.name);
        return false;
    }

    twai_onchip_node_config_t nodeConfig = {};
    nodeConfig.io_cfg.tx = (gpio_num_t)bus.txPin;
    nodeConfig.io_cfg.rx = (gpio_num_t)bus.rxPin;
    nodeConfig.io_cfg.quanta_clk_out = GPIO_NUM_NC;
    nodeConfig.io_cfg.bus_off_indicator = GPIO_NUM_NC;
    nodeConfig.bit_timing.bitrate = CAN_BITRATE;
    nodeConfig.fail_retry_cnt = 3;
    nodeConfig.tx_queue_depth = CAN_TX_QUEUE_DEPTH;

    esp_err_t err = twai_new_node_onchip(&nodeConfig, &bus.node);
    if (err != ESP_OK) {
        Serial.printf("[%s] node create failed: 0x%X\n", bus.name, err);
        return false;
    }

    if (!configureAcceptAllFilters(bus.node)) {
        Serial.printf("[%s] accept-all filter config failed\n", bus.name);
        return false;
    }

    twai_event_callbacks_t callbacks = {};
    callbacks.on_rx_done = onRxDone;
    callbacks.on_tx_done = onTxDone;
    callbacks.on_error = onError;
    callbacks.on_state_change = onStateChange;

    err = twai_node_register_event_callbacks(bus.node, &callbacks, &bus);
    if (err != ESP_OK) {
        Serial.printf("[%s] callback register failed: 0x%X\n", bus.name, err);
        return false;
    }

    err = twai_node_enable(bus.node);
    if (err != ESP_OK) {
        Serial.printf("[%s] node enable failed: 0x%X\n", bus.name, err);
        return false;
    }

    bus.started = true;
    Serial.printf("[%s] started, TX=GPIO%d RX=GPIO%d bitrate=%d bit/s\n",
                  bus.name, bus.txPin, bus.rxPin, CAN_BITRATE);
    return true;
}

static void clearCanQueue(const CanBus &bus)
{
    if (bus.rxQueue == nullptr) {
        return;
    }

    CanFrame ignored = {};
    while (xQueueReceive(bus.rxQueue, &ignored, 0) == pdTRUE) {
    }
}

static bool transmitCan(CanBus &bus, uint32_t id, const uint8_t *data, uint8_t len)
{
    bus.txFrame = {};
    bus.txFrame.header.id = id;
    bus.txFrame.header.dlc = len;
    bus.txFrame.header.ide = false;
    bus.txFrame.header.rtr = false;
    bus.txFrame.buffer = bus.txData;
    bus.txFrame.buffer_len = len;
    memcpy(bus.txData, data, len);

    const esp_err_t err = twai_node_transmit(bus.node, &bus.txFrame, pdMS_TO_TICKS(50));
    if (err != ESP_OK) {
        bus.txFail = bus.txFail + 1;
        Serial.printf("[%s] transmit failed: 0x%X\n", bus.name, err);
        return false;
    }
    return true;
}

static bool waitCanFrame(const CanBus &bus, uint32_t expectedId, CanFrame &frame,
                         uint32_t timeoutMs)
{
    const uint32_t deadline = millis() + timeoutMs;
    while ((int32_t)(millis() - deadline) < 0) {
        while (xQueueReceive(bus.rxQueue, &frame, 0) == pdTRUE) {
            if (!frame.ide && !frame.rtr && frame.id == expectedId) {
                return true;
            }
        }
        delay(1);
    }
    return false;
}

static void printCanFrame(const char *label, const CanFrame &frame)
{
    Serial.printf("[%s] ID=0x%03" PRIX32 " DLC=%u DATA=",
                  label, frame.id, (unsigned)frame.dlc);
    for (uint8_t i = 0; i < frame.dlc; ++i) {
        Serial.printf("%02X", frame.data[i]);
        if (i + 1 < frame.dlc) {
            Serial.print(' ');
        }
    }
    Serial.println();
}

static bool echoBack(uint32_t sequence)
{
    uint8_t payload[8] = {};
    CanFrame rxOnCan2 = {};
    CanFrame rxOnCan1 = {};
    fillPayload(payload, sequence);

    if (!can1.started || can1.rxQueue == nullptr ||
        !can2.started || can2.rxQueue == nullptr) {
        Serial.println("[echo] FAIL: CAN node not started");
        lastForwardOk = false;
        lastBackOk = false;
        lastEchoOk = false;
        hasEchoResult = true;
        ++echoFailCount;
        updateOledResult();
        return false;
    }

    clearCanQueue(can1);
    clearCanQueue(can2);

    if (!transmitCan(can1, CAN1_TO_CAN2_ID, payload, sizeof(payload))) {
        lastForwardOk = false;
        lastBackOk = false;
        lastEchoOk = false;
        hasEchoResult = true;
        ++echoFailCount;
        updateOledResult();
        return false;
    }

    lastForwardOk = waitCanFrame(can2, CAN1_TO_CAN2_ID, rxOnCan2, CAN_RX_TIMEOUT_MS) &&
                    verifyPayload(rxOnCan2, CAN1_TO_CAN2_ID, sequence);
    if (lastForwardOk) {
        printCanFrame("CAN1 -> CAN2", rxOnCan2);
    } else {
        Serial.println("[CAN1 -> CAN2] FAIL");
    }

    if (!lastForwardOk ||
        !transmitCan(can2, CAN2_TO_CAN1_ID, rxOnCan2.data, rxOnCan2.dlc)) {
        lastBackOk = false;
        lastEchoOk = false;
        hasEchoResult = true;
        ++echoFailCount;
        Serial.println("[echo] FAIL");
        updateOledResult();
        return false;
    }

    lastBackOk = waitCanFrame(can1, CAN2_TO_CAN1_ID, rxOnCan1, CAN_RX_TIMEOUT_MS) &&
                 verifyPayload(rxOnCan1, CAN2_TO_CAN1_ID, sequence);
    if (lastBackOk) {
        printCanFrame("CAN2 -> CAN1", rxOnCan1);
    } else {
        Serial.println("[CAN2 -> CAN1] FAIL");
    }

    lastEchoOk = lastForwardOk && lastBackOk;
    hasEchoResult = true;
    if (lastEchoOk) {
        ++echoOkCount;
        pulseOkLed();
    } else {
        ++echoFailCount;
    }

    Serial.println(lastEchoOk ? "[echo] OK" : "[echo] FAIL");
    updateOledResult();
    return lastEchoOk;
}

static void recoverIfNeeded(CanBus &bus)
{
    if (!bus.busOffSeen || bus.node == nullptr) {
        return;
    }

    twai_node_status_t status = {};
    twai_node_get_info(bus.node, &status, nullptr);
    if (status.state == TWAI_ERROR_BUS_OFF) {
        Serial.printf("[%s] bus off, start recovery\n", bus.name);
        twai_node_recover(bus.node);
        bus.started = false;
    }
    bus.busOffSeen = false;
}

static void refreshRecovered(CanBus &bus)
{
    if (bus.started || bus.node == nullptr) {
        return;
    }

    twai_node_status_t status = {};
    twai_node_get_info(bus.node, &status, nullptr);
    if (status.state == TWAI_ERROR_ACTIVE) {
        bus.started = true;
        Serial.printf("[%s] recovered\n", bus.name);
    }
}

static void processAutoSend()
{
    const uint32_t now = millis();
    if (now - lastAutoSendMs < AUTO_SEND_INTERVAL_MS) {
        return;
    }
    lastAutoSendMs = now;

    Serial.printf("\n[Test %" PRIu32 "]\n", frameSeq);
    echoBack(frameSeq++);
}

void setup()
{
    Serial.begin(115200);
    delay(500);
    Serial.println();
    Serial.println("T-C5-Base dual CAN echo-back test");
    Serial.printf("CAN1 TX=GPIO%d RX=GPIO%d, CAN2 TX=GPIO%d RX=GPIO%d, bitrate=%d bit/s\n",
                  can1.txPin, can1.rxPin, can2.txPin, can2.rxPin, CAN_BITRATE);

    initLed();
    initOled();
    drawOledBoot("STARTING");
    startCanBus(can1);
    startCanBus(can2);
    drawOledBoot("WAITING");
}

void loop()
{
    recoverIfNeeded(can1);
    recoverIfNeeded(can2);
    refreshRecovered(can1);
    refreshRecovered(can2);
    processAutoSend();
    updateOkLed();
    delay(1);
}

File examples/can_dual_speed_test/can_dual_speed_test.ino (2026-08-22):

/**
 * @file      can_speed_test.ino
 * @author    Lewis He (lewishe@outlook.com)
 * @license   MIT
 * @copyright Copyright (c) 2026  ShenZhen XinYuan Electronic Technology Co., Ltd
 * @date      2026-08-21
 * @note      T-C5-Base Shield dual CAN speed test.
 * 
 * This sketch uses the two on-chip TWAI controllers on one ESP32-C5 board.
 * Connect CAN1 and CAN2 to the same physical CAN bus so each controller can ACK
 * and receive frames from the other controller.
 *
 * Note: Arduino-ESP32 does not currently expose a native Arduino API for both
 * ESP32-C5 on-chip TWAI controllers, so this CAN example uses the ESP-IDF TWAI
 * driver APIs inside an Arduino sketch.
 * 
 * Add CAN termination according to your wiring. For a normal two-node CAN bus,
 * use 120 ohm termination at both bus ends.
*/

#include <Arduino.h>
#include <inttypes.h>
#include <string.h>
#include "SSD1306Wire.h"
#include "esp_twai.h"
#include "esp_twai_onchip.h"
#include "freertos/FreeRTOS.h"
#include "freertos/queue.h"

#define ACTIVE_CAN1 1
#define ACTIVE_CAN2 1
#define CAN_BITRATE 1000000
#define CAN1_TO_CAN2_ID 0x321
#define CAN2_TO_CAN1_ID 0x421
#define RX_QUEUE_DEPTH 128
#define TX_QUEUE_DEPTH 2
#define REPORT_INTERVAL_MS 1000
#define LOOP_YIELD_MS 1
#define OLED_I2C_ADDRESS 0x3C
#define OLED_SDA_PIN 2
#define OLED_SCL_PIN 3

#if !ACTIVE_CAN1 || !ACTIVE_CAN2
#error "This dual speed test needs both ACTIVE_CAN1 and ACTIVE_CAN2 enabled."
#endif

// CAN1 pins
#define CAN1_TX_PIN 26
#define CAN1_RX_PIN 25
// CAN2 pins
#define CAN2_TX_PIN 0
#define CAN2_RX_PIN 1

struct CanFrame {
  uint32_t id;
  uint8_t dlc;
  bool ide;
  bool rtr;
  uint8_t data[TWAI_FRAME_MAX_LEN];
};

struct CanBus {
  const char *name;
  int txPin;
  int rxPin;
  uint32_t txId;
  uint32_t expectedRxId;
  uint8_t txMarker;
  uint8_t expectedRxMarker;
  twai_node_handle_t node;
  QueueHandle_t rxQueue;
  twai_frame_t txFrame;
  uint8_t txData[TWAI_FRAME_MAX_LEN];
  volatile bool txBusy;
  volatile bool busOffSeen;
  volatile uint32_t isrDrops;
  volatile uint32_t txFrames;
  volatile uint32_t txBytes;
  volatile uint32_t txFailed;
  volatile uint32_t busErrors;
  bool started;
  uint32_t txSequence;
  uint32_t expectedRxSequence;
  uint32_t rxFrames;
  uint32_t rxBytes;
  uint32_t goodFrames;
  uint32_t badFrames;
  uint32_t unexpectedFrames;
  uint32_t rxQueueDrops;
  uint32_t busOffCount;
};

struct CanReport {
  const char *name;
  uint32_t txFrameRate;
  uint32_t txByteRate;
  uint32_t rxFrameRate;
  uint32_t rxByteRate;
  uint32_t goodFrames;
  uint32_t badFrames;
  uint32_t unexpectedFrames;
  uint32_t txFailed;
  uint32_t isrDrops;
  uint32_t rxQueueDrops;
  uint32_t busErrors;
  uint32_t recordBusErrors;
  uint32_t busOffCount;
  twai_error_state_t state;
  uint8_t txErrorCount;
  uint8_t rxErrorCount;
  bool pass;
};

static CanBus can1 = {
    "CAN1", CAN1_TX_PIN, CAN1_RX_PIN, CAN1_TO_CAN2_ID, CAN2_TO_CAN1_ID, 0xA1, 0xB2,
    nullptr, nullptr, {}, {}, false, false, 0, 0, 0, 0, 0, false,
    0, 0, 0, 0, 0, 0, 0, 0, 0};

static CanBus can2 = {
    "CAN2", CAN2_TX_PIN, CAN2_RX_PIN, CAN2_TO_CAN1_ID, CAN1_TO_CAN2_ID, 0xB2, 0xA1,
    nullptr, nullptr, {}, {}, false, false, 0, 0, 0, 0, 0, false,
    0, 0, 0, 0, 0, 0, 0, 0, 0};

static uint32_t lastReportMs = 0;
static SSD1306Wire oled(OLED_I2C_ADDRESS, OLED_SDA_PIN, OLED_SCL_PIN);
static bool oledReady = false;
static bool oledStatusValid = false;
static bool oledLastPass = false;
static bool oledLastPass1 = false;
static bool oledLastPass2 = false;

static uint8_t checksumPayload(const uint8_t *data, size_t len) {
  uint8_t sum = 0x5A;
  for (size_t i = 0; i < len; ++i) {
    sum = (uint8_t)((sum << 1) | (sum >> 7));
    sum ^= data[i];
  }
  return sum;
}

static void fillPayload(CanBus &bus) {
  const uint32_t sequence = bus.txSequence++;
  bus.txData[0] = bus.txMarker;
  memcpy(&bus.txData[1], &sequence, sizeof(sequence));
  bus.txData[5] = (uint8_t)~bus.txMarker;
  bus.txData[6] = (uint8_t)(sequence ^ (sequence >> 8) ^ (sequence >> 16) ^ (sequence >> 24));
  bus.txData[7] = checksumPayload(bus.txData, 7);
}

static bool verifyPayload(CanBus &bus, const CanFrame &frame) {
  if (frame.ide || frame.rtr || frame.id != bus.expectedRxId || frame.dlc != 8) {
    ++bus.unexpectedFrames;
    return false;
  }

  uint32_t sequence = 0;
  memcpy(&sequence, &frame.data[1], sizeof(sequence));

  const bool payloadOk =
      frame.data[0] == bus.expectedRxMarker &&
      frame.data[5] == (uint8_t)~bus.expectedRxMarker &&
      frame.data[6] == (uint8_t)(sequence ^ (sequence >> 8) ^ (sequence >> 16) ^ (sequence >> 24)) &&
      frame.data[7] == checksumPayload(frame.data, 7);

  if (!payloadOk) {
    return false;
  }

  if (sequence != bus.expectedRxSequence) {
    bus.expectedRxSequence = sequence + 1;
    return false;
  }

  ++bus.expectedRxSequence;
  return true;
}

static bool IRAM_ATTR onRxDone(twai_node_handle_t handle,
                               const twai_rx_done_event_data_t *eventData,
                               void *userContext) {
  (void)eventData;
  CanBus *bus = (CanBus *)userContext;

  uint8_t rxData[TWAI_FRAME_MAX_LEN] = {};
  twai_frame_t rxFrame = {};
  rxFrame.buffer = rxData;
  rxFrame.buffer_len = sizeof(rxData);

  BaseType_t taskWoken = pdFALSE;
  if (twai_node_receive_from_isr(handle, &rxFrame) != ESP_OK) {
    bus->isrDrops = bus->isrDrops + 1;
    return taskWoken == pdTRUE;
  }

  CanFrame queuedFrame = {};
  queuedFrame.id = rxFrame.header.id;
  queuedFrame.dlc = rxFrame.header.dlc > TWAI_FRAME_MAX_LEN ? TWAI_FRAME_MAX_LEN : rxFrame.header.dlc;
  queuedFrame.ide = rxFrame.header.ide;
  queuedFrame.rtr = rxFrame.header.rtr;
  memcpy(queuedFrame.data, rxData, queuedFrame.dlc);

  if (xQueueSendFromISR(bus->rxQueue, &queuedFrame, &taskWoken) != pdTRUE) {
    bus->rxQueueDrops = bus->rxQueueDrops + 1;
  }

  return taskWoken == pdTRUE;
}

static bool IRAM_ATTR onTxDone(twai_node_handle_t handle,
                               const twai_tx_done_event_data_t *eventData,
                               void *userContext) {
  (void)handle;
  CanBus *bus = (CanBus *)userContext;

  if (eventData->is_tx_success) {
    bus->txFrames = bus->txFrames + 1;
    bus->txBytes += eventData->done_tx_frame->buffer_len;
  } else {
    bus->txFailed = bus->txFailed + 1;
  }
  bus->txBusy = false;

  return false;
}

static bool IRAM_ATTR onError(twai_node_handle_t handle,
                              const twai_error_event_data_t *eventData,
                              void *userContext) {
  (void)handle;
  CanBus *bus = (CanBus *)userContext;
  if (eventData->err_flags.val) {
    bus->busErrors = bus->busErrors + 1;
  }
  return false;
}
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
